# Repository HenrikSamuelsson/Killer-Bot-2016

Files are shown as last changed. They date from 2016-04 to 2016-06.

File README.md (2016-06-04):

# Killer-Bot-2016
Drawings for office robot competition 2016.

## Electronics  
A [NUCLEO-F411RE](https://developer.mbed.org/platforms/ST-Nucleo-F411RE/) is used as primary controller.  

The NUCLEO board can be powered by USB from a computer or from a external power supply. Allowed external voltage range is 7 V to 12 V. This project will run at 12 V. The maximum allowed input current is then 250 mA. The board is configured for external power by setting jumper JP5 on pin 2 and 3, JP1 shall additionally be removed.  

## Tracks
The tracks are based around a roller chain of type DIN 8187:1984 Short pitch. Distance (p) between pins 9.525 mm. Roller diameter (d) max 6.350 mm.

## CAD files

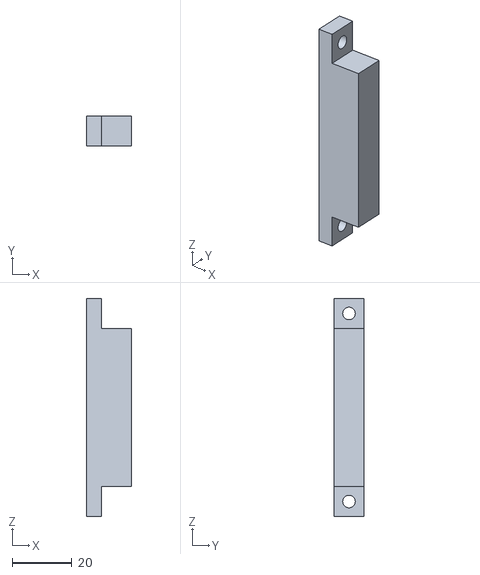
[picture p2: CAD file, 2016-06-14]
AutodeskWorkspace/robotparts revision 2/frontBeam.stl
15.0 x 10.0 x 73.0

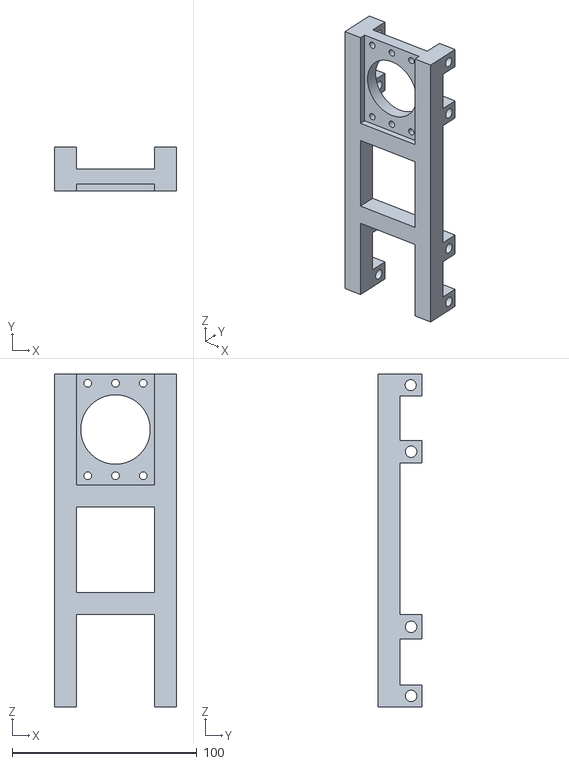
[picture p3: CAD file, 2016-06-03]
printfiles/framesideRight.stl
66.0 x 24.0 x 180.0

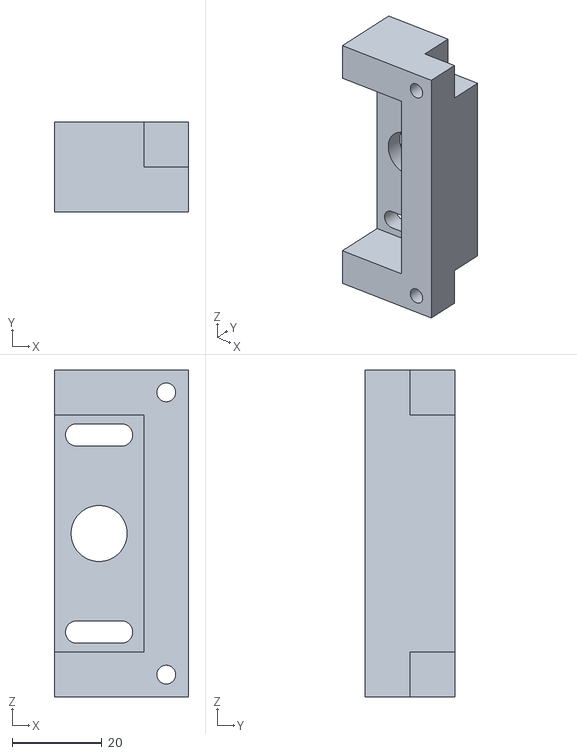
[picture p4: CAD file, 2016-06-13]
AutodeskWorkspace/robotparts revision 2/powerSwitchHolder.stl
30.0 x 20.0 x 73.0

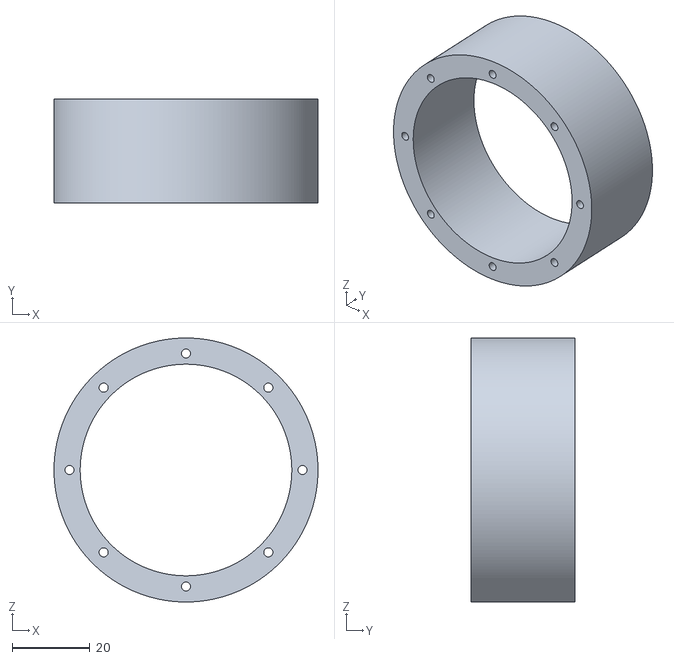
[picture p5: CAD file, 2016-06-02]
printfiles/sprocketsHolder.stl
68.0 x 26.7 x 68.0

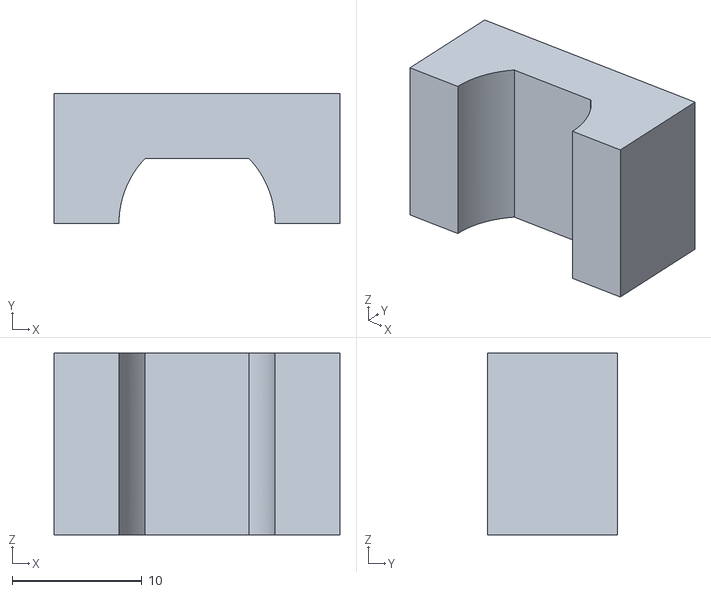
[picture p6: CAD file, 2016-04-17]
AutodeskWorkspace/motorHolderTest1.stl
22.0 x 10.0 x 14.0

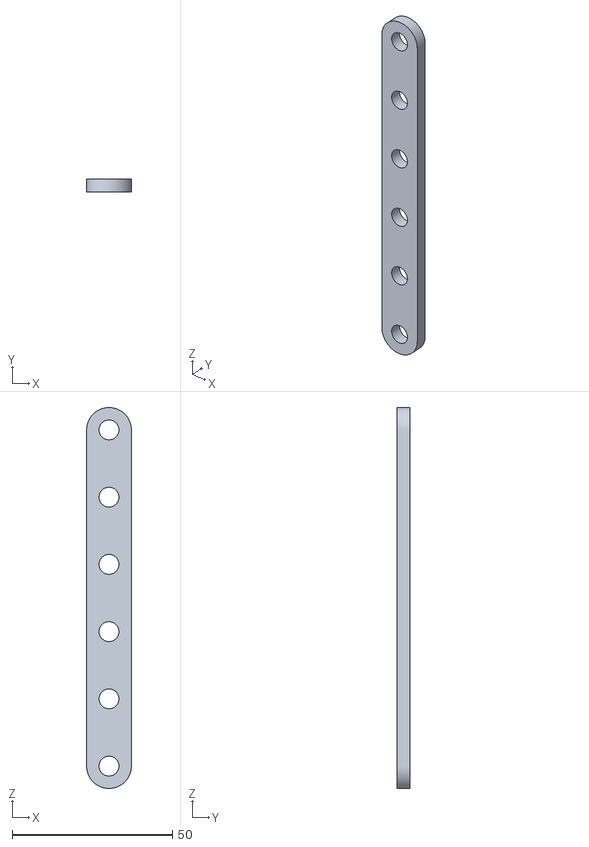
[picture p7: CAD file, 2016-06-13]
AutodeskWorkspace/robotparts revision 2/axlefixture.stl
14.0 x 4.00 x 119.0

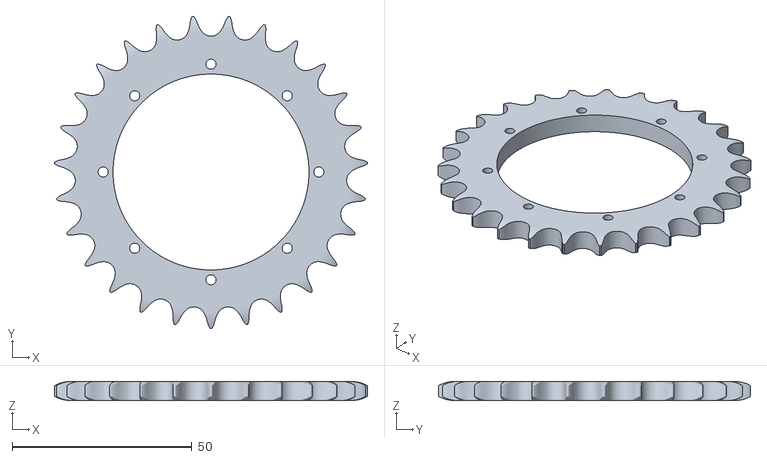
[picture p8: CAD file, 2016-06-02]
printfiles/BigSprocket2.stl
87.1 x 86.9 x 5.32

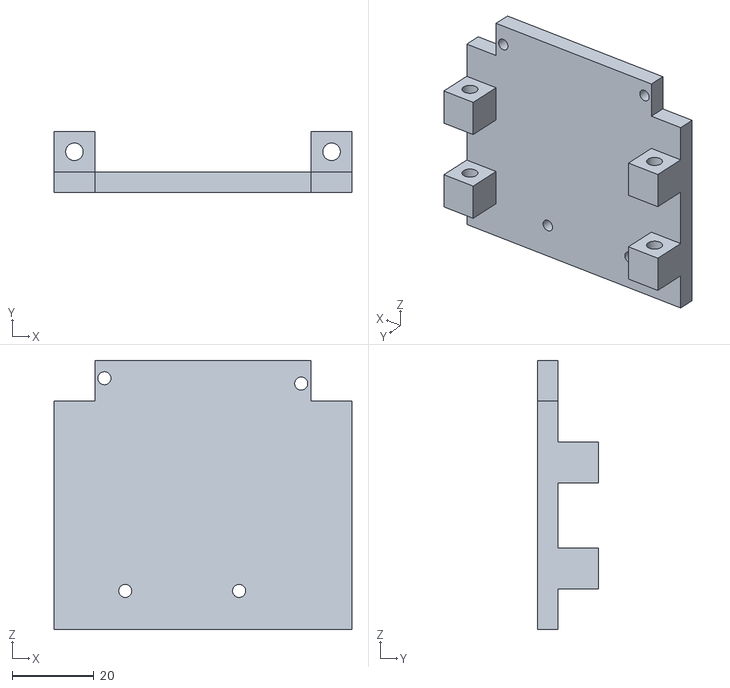
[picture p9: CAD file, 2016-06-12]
AutodeskWorkspace/robotparts revision 2/arduinoPlate.stl
73.0 x 15.0 x 66.0

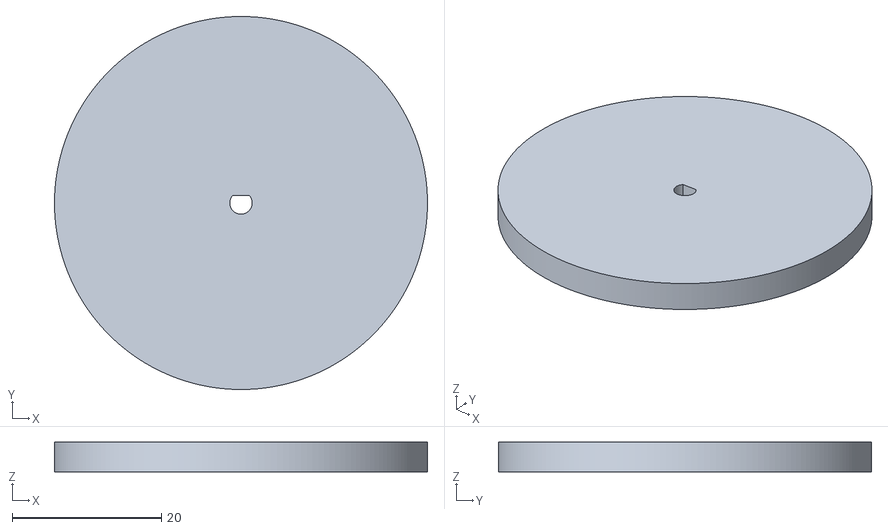
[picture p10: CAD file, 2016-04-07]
AutodeskWorkspace/wheel.stl
50.0 x 50.0 x 4.00

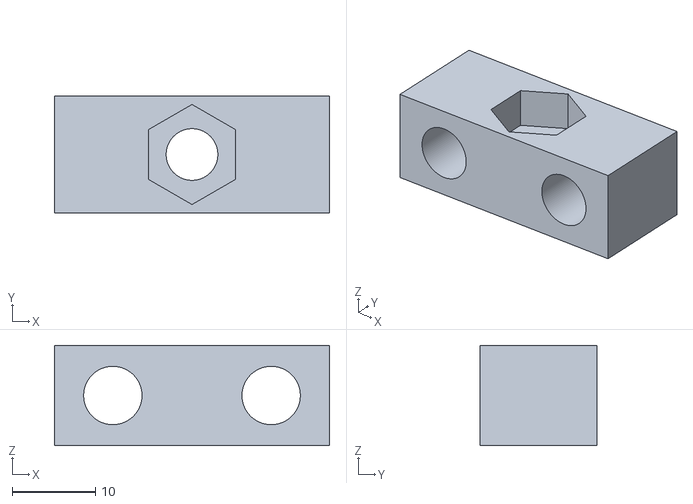
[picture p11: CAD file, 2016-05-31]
printfiles/smallSprocketFixture.stl
33.0 x 14.0 x 12.0

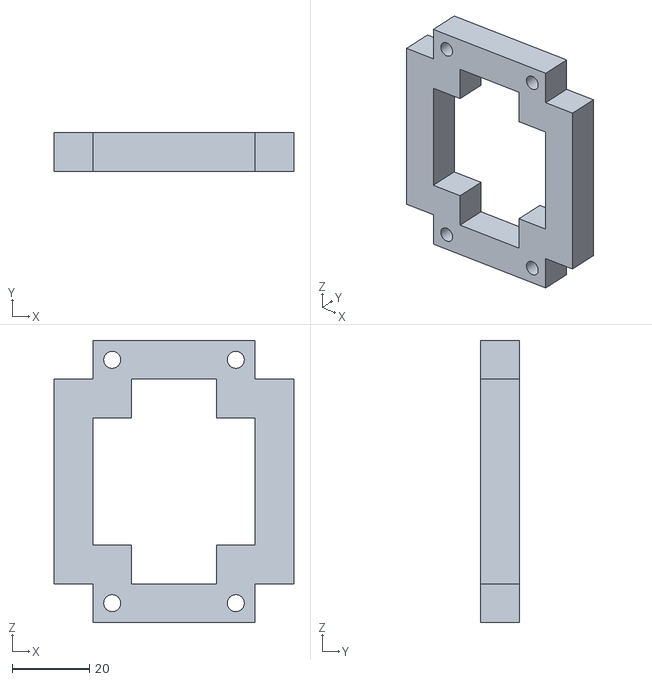
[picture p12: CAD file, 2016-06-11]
AutodeskWorkspace/robotparts revision 2/bottomplate.stl
62.0 x 10.0 x 73.0

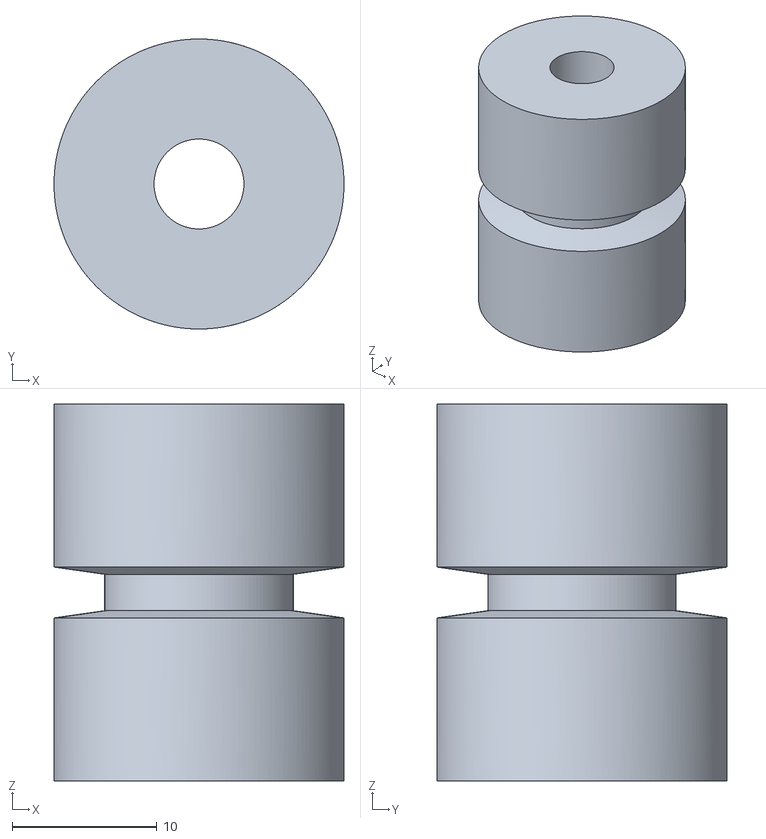
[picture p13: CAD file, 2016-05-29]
printfiles/roller.stl
20.0 x 20.0 x 26.0

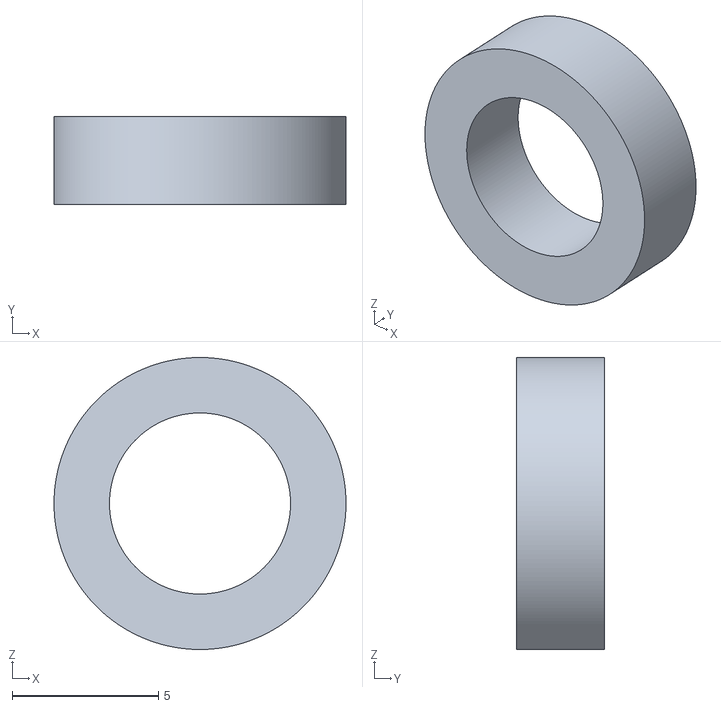
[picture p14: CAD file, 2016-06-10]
AutodeskWorkspace/robotparts revision 2/outerDistance.stl
10.00 x 3.00 x 10.00

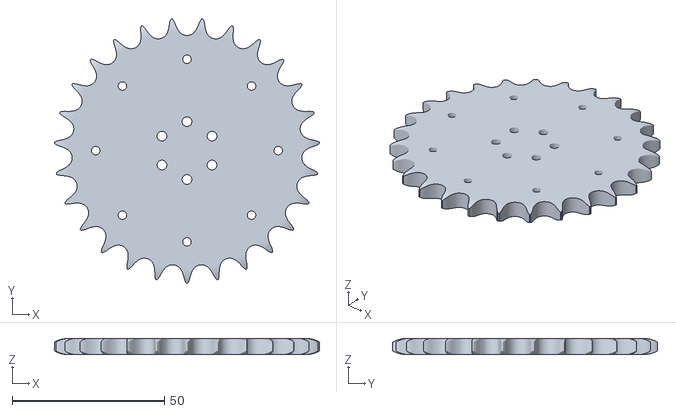
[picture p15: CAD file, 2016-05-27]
printfiles/outerBigSprocket2.stl
87.1 x 86.9 x 5.32

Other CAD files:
AutodeskWorkspace/tracks.dwg
AutodeskWorkspace/servo.dwg
AutodeskWorkspace/robotparts revision 2/bottomSideFrame1.stl
printfiles/motorHolder57mm.stl
AutodeskWorkspace/57mmTest.iam
AutodeskWorkspace/57mmTest/Design Accelerator/Chain Drive1.iam
AutodeskWorkspace/57mmTest/Design Accelerator/Chain Drive2.iam
AutodeskWorkspace/57mmTest/Design Accelerator/Chain Drive3.iam
AutodeskWorkspace/57mmTest/Design Accelerator/OldVersions/Chain Drive2.0001.iam
AutodeskWorkspace/57mmTest/Design Accelerator/OldVersions/Roller Chain Sprocket12.0001.ipt
AutodeskWorkspace/57mmTest/Design Accelerator/Roller Chain Sprocket11.ipt
AutodeskWorkspace/57mmTest/Design Accelerator/Roller Chain Sprocket12.ipt
AutodeskWorkspace/57mmTest/Design Accelerator/Roller Chain Sprocket13.ipt
AutodeskWorkspace/57mmTest/Design Accelerator/Roller Chain Sprocket21.ipt
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

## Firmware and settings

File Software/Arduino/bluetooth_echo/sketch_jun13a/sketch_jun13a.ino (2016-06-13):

/*************************************************************
Motor Shield 2-Channel DC Motor Demo
by Randy Sarafan

For more information see:
http://www.instructables.com/id/Arduino-Motor-Shield-Tutorial/

*************************************************************/

void setup() {
  
  //Setup Channel A
  pinMode(12, OUTPUT); //Initiates Motor Channel A pin
  pinMode(9, OUTPUT); //Initiates Brake Channel A pin

  //Setup Channel B
  pinMode(13, OUTPUT); //Initiates Motor Channel A pin
  pinMode(8, OUTPUT);  //Initiates Brake Channel A pin
  
}

void loop(){

  
  //Motor A forward @ full speed
  digitalWrite(12, HIGH); //Establishes forward direction of Channel A
  digitalWrite(9, LOW);   //Disengage the Brake for Channel A
  analogWrite(3, 255);   //Spins the motor on Channel A at full speed

  //Motor B forward @ full speed
  digitalWrite(13, HIGH);  //Establishes forward direction of Channel B
  digitalWrite(8, LOW);   //Disengage the Brake for Channel B
  analogWrite(11, 255);    //Spins the motor on Channel B at half speed

  
  delay(2000);

  
  digitalWrite(9, HIGH);  //Engage the Brake for Channel A
  digitalWrite(9, HIGH);  //Engage the Brake for Channel B


  delay(500);
  
  
  //Motor A forward @ full speed
  digitalWrite(12, LOW);  //Establishes backward direction of Channel A
  digitalWrite(9, LOW);   //Disengage the Brake for Channel A
  analogWrite(3, 123);    //Spins the motor on Channel A at half speed
  
  //Motor B forward @ full speed
  digitalWrite(13, LOW); //Establishes backward direction of Channel B
  digitalWrite(8, LOW);   //Disengage the Brake for Channel B
  analogWrite(11, 255);   //Spins the motor on Channel B at full speed
  
  
  delay(2000);
  
  
  digitalWrite(9, HIGH);  //Engage the Brake for Channel A
  digitalWrite(9, HIGH);  //Engage the Brake for Channel B
  
  
  delay(500);
  
}

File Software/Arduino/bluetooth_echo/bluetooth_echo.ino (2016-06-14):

String message; //string that stores the incoming message

void setup()
{
  Serial.begin(9600); //set baud rate
}

void loop()
{
  
  if (Serial.available() > 0) {
  int inByte = Serial.read();
    // do something different depending on the character received.
    // The switch statement expects single number values for each case;
    // in this exmaple, though, you're using single quotes to tell
    // the controller to get the ASCII value for the character.  For
    // example 'a' = 97, 'b' = 98, and so forth:

    switch (inByte) {
      case 'a':
        digitalWrite(2, HIGH);
        break;
      case 'b':
        digitalWrite(3, HIGH);
        break;
      case 'c':
        digitalWrite(4, HIGH);
        break;
      case 'd':
        digitalWrite(5, HIGH);
        break;
      case 'e':
        digitalWrite(6, HIGH);
        break;
      default:
        // turn all the LEDs off:
        for (int thisPin = 2; thisPin < 7; thisPin++) {
          digitalWrite(thisPin, LOW);
        }
    }
}
}

    

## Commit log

2016-04-07 Adds first version of a wheel for the bot.
    [Part1.ipt, wheel.ipt, wheel.stl]
2016-04-07 Tested to make some holes in the wheel.
    [wheel.ipt]
2016-04-12 Adds part for holding electrical motors in place.
    [motorHolderTest1.ipt, motorHolderTest1.stl]
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2016-04-15 Adds drawing of the servo to be used for the hammers.
    [servo.dwg]
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2016-04-17 Modifications to the servo holder to have better fit with the screw holes.
    [servoHolderTest1.ipt, servoHolderTest1.stl]
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2016-04-18 More work on the part that will form the tracks of the bot.
    [tracks.ipt, tracks.stl]
2016-04-19 Fixes of the tracks
    [tracks.ipt, tracks.stl]
2016-04-20 Adds a vertical standout to help keep the tracks centered on the wheels.
    [tracks.ipt, tracks.stl]
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2016-04-23 Made a drawing of current version of the tracks.
    [tracks.dwg, tracks.ipt]
2016-04-24 Adds a mounting hub that for connecting motor and a wheel or sprocket.
    [mountingHub6mm.ipt]
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2016-04-27 Adds a sprocket that is a promising candidate for driving the tracks.
    [driveSprocket.ipt, driveSprocket.stl]
2016-04-28 Started on second version of the tracks that shall fit the on the new sprocket.
    [tracks.dwg, tracks2.ipt]
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2016-05-03 Adds print files for the roller chain test.
    [tracks_center.stl]
2016-05-04 Updates of the tracks, larger center hole with chamfer.
    [tracks_center.ipt, tracks_center.stl, tracks_outer.ipt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]
2016-05-06 Added a bevel to the center parts of the tracks.
    [tracks_center.ipt, tracks_center.stl]
2016-05-06 Center hole in the tracks still a bit too small so made it 0.1mm larger.
    [tracks_center.ipt, tracks_center.stl]
2016-05-08 Larger center hole again and some print files for printing multiple units.
    [tracks_center.ipt, tracks_center.stl]
2016-05-09 adds motor holder for the 57 mm motor.
    [motorHolder57mm.ipt]
2016-05-10 Adds printfiles for the 57 mm motor holder.
    [motorHolder57mm.stl]
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2016-05-10 0.2 mm larger diameter for the screw holes.
    [motorHolder57mm.ipt]
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2016-05-11 Adds some printfiles that are candidate for a new drive sprocket.
    [BigSprocket2.stl]
2016-05-11 Adds start of model of the gear motor type that will be used to drive the tracks.
    [37D mm metal gearmotor.ipt]
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2016-05-14 New holder of the motor and started on assembly.
    [motorHolder57mmVer2.ipt, motorHolder57mmVer2.stl, robotassembly1.iam]
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2016-05-15 Worked on part to connect the big sprockets.
    [Assembly1.iam, Assembly4.iam, BigSprocket2.ipt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]
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2016-05-16 Had to redesign and have a new outer sprocket that will look different than the inner sprocket.
    [outerBigSprocket2.ipt]
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2016-05-18 Started on the frame for the right side.
    [framesideRight.ipt, motorHolder57mmVer2.ipt, robotassembly1.iam]
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2016-05-20 some fixes on the right frame.
    [framesideRight.ipt, framesideRight.stl]
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2016-05-22 Udate that moves the small sprocket 12 mm outwards.
    [frameBack.ipt, framesideRight.ipt, motorHolder57mmVer2.ipt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]
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2016-05-24 Changed the pin to its actual measured size.
    Will have to change some other parts as well later on.
    [pin5x60.ipt, robotassembly1.iam]
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2016-05-25 Repairing some stuff that I have broken.
    [framesideRight.ipt, robotassembly1.iam]
2016-05-25 Adds roller wheels and bottom part of the frame.
    [frameBottomRight.ipt, robotassembly1.iam, roller.ipt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]
2016-05-26 smaller distance between the drive sprocket and the rollers.
    [frameBottomRight.ipt, robotassembly1.iam]
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2016-05-28 Shall use a shorter pin so modified the current version.
    [pin5x60.ipt]
2016-05-28 Adjustment for short pin.
    [framesideRight.ipt]
2016-05-28 Assembly updated with shorter pin.
    [robotassembly1.iam]
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2016-05-28 Fix of diameter and color of the outer small sprocket.
    [outerSmallSprocket.ipt, smallSprocket2.stl]
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2016-05-29 Print files for the roller. Slightly smaller hole diameter for the roller.
    [roller.ipt, roller.stl]
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2016-05-30 Adding some missing constraints.
    [robotassembly1.iam]
2016-05-30 Made a hole for fixturing of a nut.
    [smallSprocketFixture.ipt]
2016-05-30 Had to make the frame bottom higher to prevent if from colliding with the drive sprocket.
    [frameBottomRight.ipt, robotassembly1.iam]
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2016-05-30 Adds part that will keep the rollers at the correct distance from the frame
    [rollerdistance.ipt]
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2016-05-30 Adds a nut for the smallsprocket fixture.
    [robotassembly1.iam]
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2016-05-31 Made the holes in the small sprocket fixture slightly bigger for better fit of the metal parts.
    [smallSprocketFixture.ipt, smallSprocketFixture.stl]
2016-05-31 Adjusting hole positions to fit the latest version of the small sprocket fixture.
    [frameBack.ipt, framesideRight.ipt, robotassembly1.iam]
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2016-06-01 Bit longer since the distance between the frame and the roller have increased.
    [motorHolder57mmVer2.ipt, rollerdistance.ipt]
2016-06-01 Updates to assembly because have moved the tracks longer away from the frame. Have also decided how to fit the battery.
    [robotassembly1.iam]
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2016-06-01 new distance to be used between the frame and the small sprocket.
    [rollerdistanceShort.ipt]
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2016-06-02 Slightly larger clearance between the motor and the big sprocket parts. Tighter screw holes in the central part of the sprocket.
    [BigSprocket2.ipt, BigSprocket2.stl, sprocketsHolder.ipt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]
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2016-06-05 Adds a marker on the sprocket to be able to see how the mate it with the sister sprocket.
    [outerBigSprocket2.ipt]
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2016-06-05 Adds a cutout to be able to fit the battery inside the protective frame.
    [sideFrame.ipt]
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2016-06-05 Fix of wrong height for this part.
    [backFrame.ipt]
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2016-06-05 Adds new version of the small sprocket fixture. Kind of the same design but cleaner sketches.
    [smallSprocketFixture.ipt]
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2016-06-05 Rotating the back frame around because I put the new holes on the wrong side.
    [Assembly1.iam, backFrame.ipt, sideFrame.ipt]
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2016-06-05 Adds the small sprocket fixture to the assembly.
    [Assembly1.iam, smallSprocketFixture.ipt]
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2016-06-05 Correcting orientation of small sprocket fixture.
    [Assembly1.iam]
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2016-06-05 Adjusting suspension height.
    Note to self would be better to have 35 mm distance on each side since the parts would be more symmetric, but this would infer some other changes.
    [sideFrame2.ipt]
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2016-06-05 Adds screws and nuts to hold the second frame side in place.
    [Assembly1.iam]
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2016-06-05 Placing of second small sprocket fixture.
    [Assembly1.iam]
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2016-06-05 Fix for incorrect constraint.
    [Assembly1.iam]
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2016-06-05 Adds missing nuts and washers for the back frame.
    [Assembly1.iam]
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2016-06-06 Made a hole in the middle to cut down on the print time a bit.
    [backFrame.ipt]
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2016-06-06 Adds missing screw hole.
    [bottomSideFrame.ipt]
2016-06-06 Unknown changes program crashed.
    [bottomSideFrame.ipt]
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2016-06-06 Trying to fix problem with redundant point, not quite fixed yet.
    [bottomSideFrame.ipt]
2016-06-06 Moving holes down 3 mm to avoid mounting problems with some of the nuts.
    [bottomSideFrame.ipt]
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2016-06-06 Thinner battery supports to avoid some mounting problems.
    [bottomSideFrame.ipt]
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2016-06-06 Even more mounting holes, never know what we want to attach next.
    [bottomSideFrame.ipt]
2016-06-06 Moving holes down to avoid mounting problems.
    [bottomSideFrame.ipt]
2016-06-06 Notice that it would actually be better to place the bottom on the top of the construction so moved it here and turned the battery around.
    [Assembly1.iam, bottomSideFrame.ipt]
2016-06-06 Needed to move holes down to be able to mount all the screws.
    [bottomSideFrame.ipt]
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2016-06-06 Removing parts that are out of place because the design have changed.
    [Assembly1.iam]
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2016-06-08 Changed to right extruder because had a little problem with the last print.
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2016-06-10 Adds the missing bottom part to the assembly.
    [Assembly1.iam]
2016-06-10 Adds an extra distance to be able to fit axels for the rollers.
    [Assembly1.iam]
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2016-06-10 Adds a bult on the opposite side to check that it fits.
    [Assembly1.iam]
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2016-06-14 Add a simple controller software for the bot, and one new part.
    [Assembly1.iam, frontBeam.ipt, frontBeam.stl]
2016-06-30 Starting out with now folder that will hold screws, nuts and washers.
    [machineScrew3x15.ipt]
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2016-06-30 New type of motor fixture.
    [motor fixture.ipt]
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2016-06-30 Placing of washers used to mount the motor in the motor fixture.
    [botAssemblyVer3.iam]
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
